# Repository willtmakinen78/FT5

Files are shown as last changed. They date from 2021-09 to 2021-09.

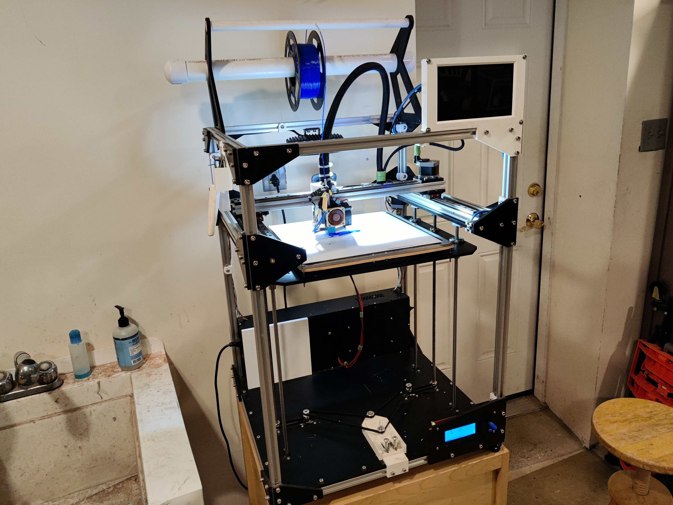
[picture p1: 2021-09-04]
pics/IMG_20210827_170959.jpg

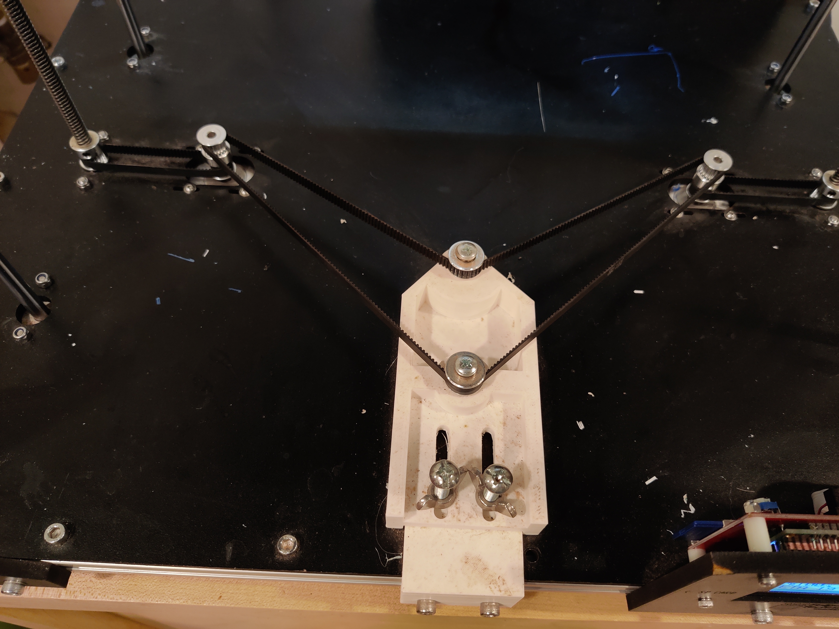
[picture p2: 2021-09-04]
pics/IMG_20210827_171039.jpg

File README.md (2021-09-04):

# FT5
My Very first 3D printer, this is a brief overview of the modifications I've made to my Folgertech FT-5 over the years.

Like the [BCN3D Sigma](https://github.com/willtmakinen78/BCN3DSigma), my work on this machine has been somewhat haphazard and disjointed, so I've done mmy best to collect the most recent version of things here. As my very first machine, this printer has gone through a lot, with many different changes made over the years, both big and small. It was a great learning platform, as it is quite large (300mmx300mmx500mm build volume) with a very open frame, and lent itself quite well to be used for my HIgh school Junior year science fair project which you can check out [here](https://github.com/willtmakinen78/sciencefair2017). If you compare the pcitures between the two, you could somewhat track how it's changed over the years.

#### Here is a list of (most) of the changes I've made:
- Replaced extruder with the E3D Hemera
  - perhaps it's because I'm an E3D shill due to my interning with them, but this is a really great extruder. After going through the stock extruder, the E3D Titan Aero, and a Bondtech Extruder, this has proved to be the best one yet, with the most consistently-good print quality.
  - This is also accompanied by a custom layer fan duct due to the non-standard mounting, similar to the ones on my Sigma printer.
  - an entirely new 3d printed extruder mount was also needed.
 - Aluminum bed mount and BuildTak FlexPlate System
  - the aluminum bed mount provides a super flat base surface for the silicone heater (also added) and the FlexPlate allows for induction probing and easy-to-remove prints
- Induction probe for automatic bed leveling
  - given the era of the FT5 and its price, I don't blame Folgertech too much for not including auto med leveling. After running a BLTouch for a number of years, I wanted something that wouldn't get destroyed if the probe was accidentally left out while an illegal move was being made, so the induction probe is a great solution with no moving parts that triggers perfectly well with the metal FlexPlate.
- Larger overhead spool holder
  - Another feature that has gone through many different iterations, this spolholder, of a size that could only be printed on the FT-5 itself, is finally something that I'm really statisfied with. The bowden tube also prevents the spools from unspooling when you let go of the filament, which is a nice feature.
- Unified Z-axis
  - this one was pulled straight from Thingiverse, but it's a nice little touch that ensures the two Z motors are always moving in sync.
- Integrated RaspberryPi with 7in touch screen
  - I love being able to control my printers from the machines themselves, and this giant touchscreen with a pi running Repeteier Host makes that super easy. It also looks really cool.
- ATX power supply
  - the standard PSU died on me, so I went all out and bought an ATX PSU to replace it (it's a 12V printer). It also has RGB.
- Added TMC2130 stepper drivers
  - replaced the default A4988s with the trinamics to allow for super quiet StealthChop operation and SPI/software-controlled motor currents.
- Improved cable management and wiring harness to the extruder
  - replaced the heavy and drag-prone cable chains with a single wire bundle wrapped in a nice braided sleeve.
- Added print light
  - this is ther same light used for the science fair project. It's meant to be mounted to cars as an auxillary headlight so it's super bright and makes it really easy to see what you're doing and illuminates things very well for the webcam connected to Repetier Host.
- Fully custom Marlin configuration
  - done to keep things updated to the most recent version. The default firware was luckily also a pretty stock Marlin, but Folgertech never really sent out too many updates.
- Fully custom PrusaSlicer Settings
  - This machine has printed GCode from almost any slicer imagineable (Slic3r, Cura, Simplify3D), however PrusaSlicer is my current favorite due to how it handles the differences between machines, gneral print settings, and materials.
- Unified white printed parts
  - tool holders, wire clips, etc. The little things.

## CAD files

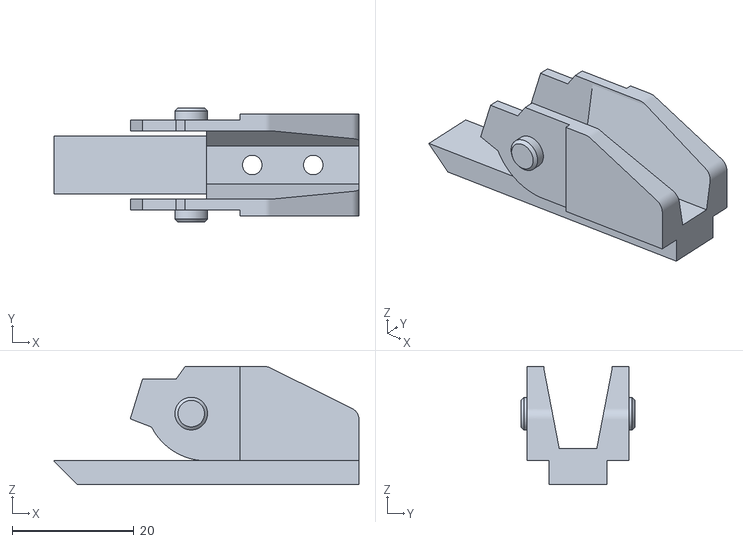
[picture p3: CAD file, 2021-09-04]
cad/Cable_Chain_Mount/Cable_Chain_Mount.stl
50.0 x 18.8 x 19.3

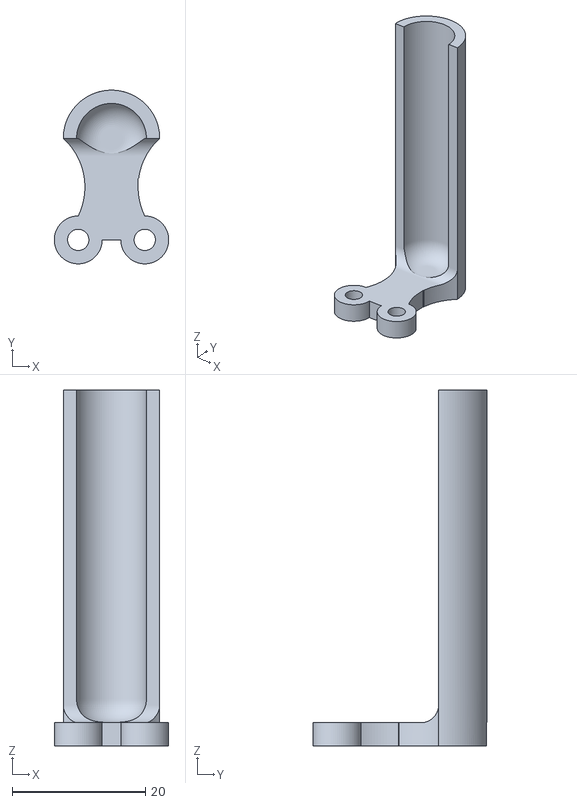
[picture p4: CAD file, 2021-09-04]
cad/Filament_Holders/Extruder_Wire_Holder_R1_1.stl
17.2 x 26.1 x 53.5

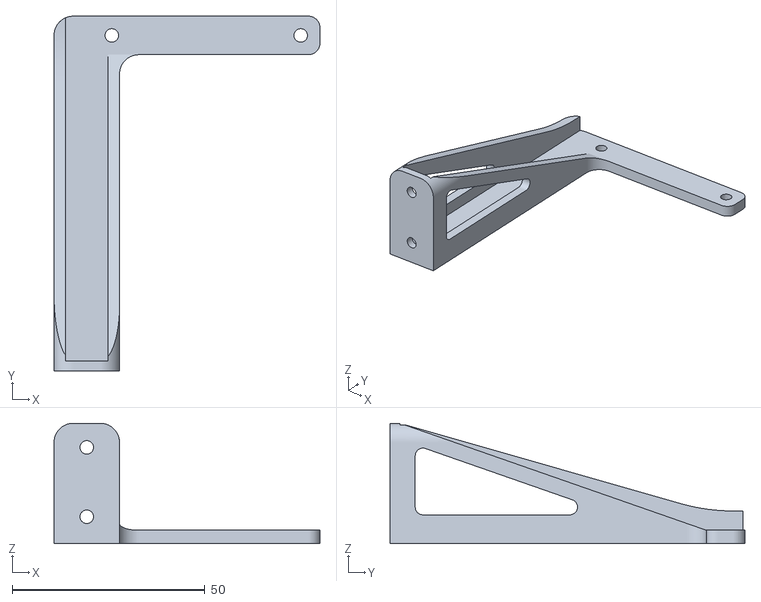
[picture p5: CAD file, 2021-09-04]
cad/FT5_BLTouch_Mount_BMG_Metal_Reinforced/FT5_BLTouch_Mount_BMG_Metal_Reinforced_2.stl
69.0 x 92.0 x 31.2

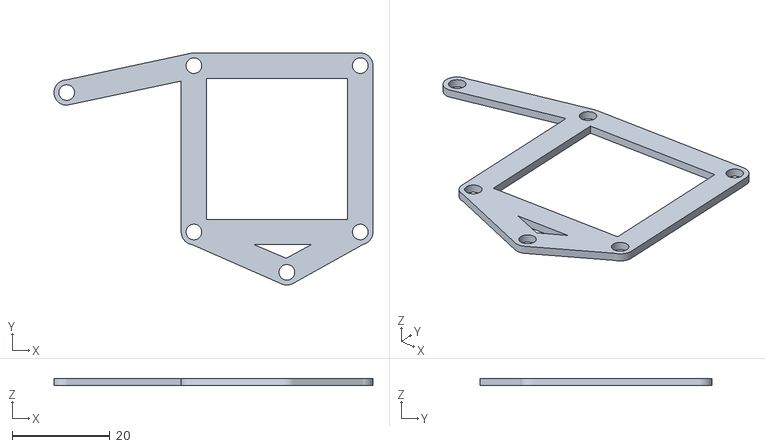
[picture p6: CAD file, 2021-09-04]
cad/Hermes_Mount/Hermes_LayerFan_Mount/Hermes_LayerFan_Mount_Test_1.stl
65.2 x 47.4 x 1.50

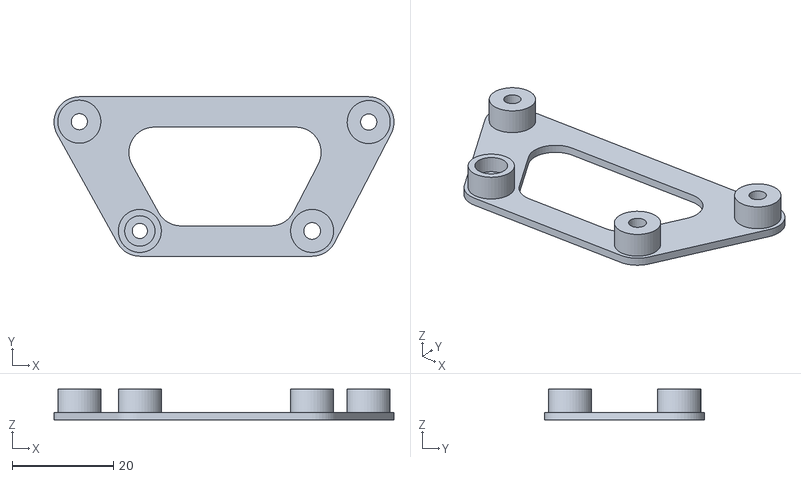
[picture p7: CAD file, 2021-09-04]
cad/Hermes_Mount/Hermes_Mount_Fan/Hemera_5015_FanMount_redangel1984.stl
67.1 x 31.5 x 6.10

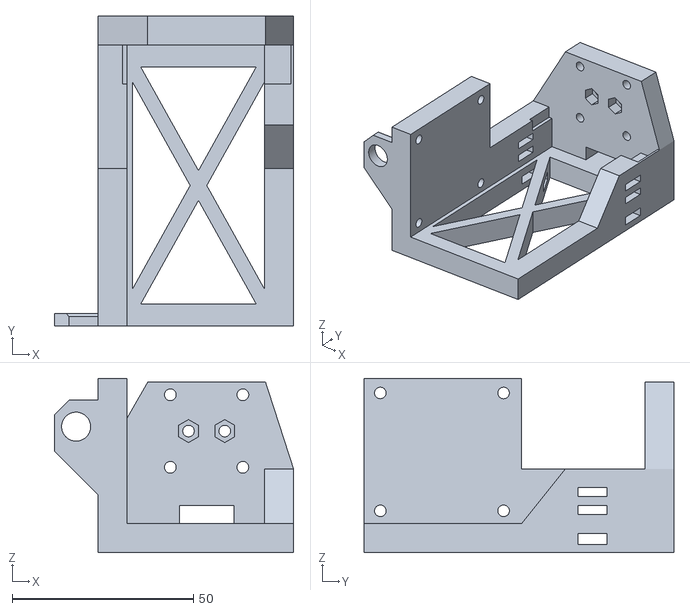
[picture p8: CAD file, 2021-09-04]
cad/Hermes_Mount/Hermes_Mount_Frame/Hermes_Mount_R3.stl
66.0 x 85.5 x 48.0

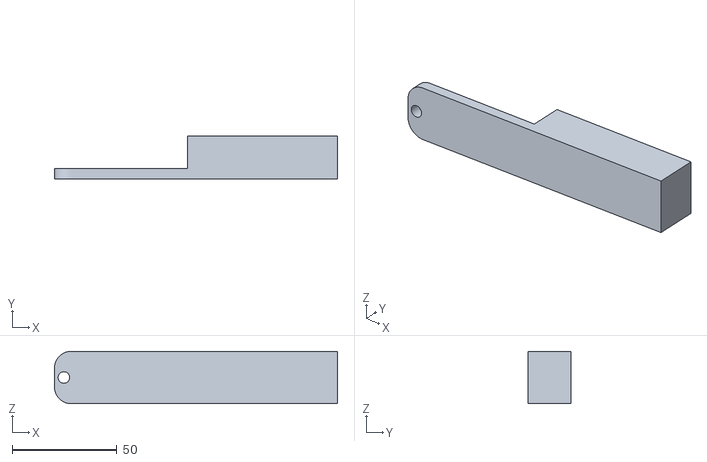
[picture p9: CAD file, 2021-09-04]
cad/Pliers_Holder/Pliers_Holder_Big_1.stl
135.0 x 20.5 x 25.0

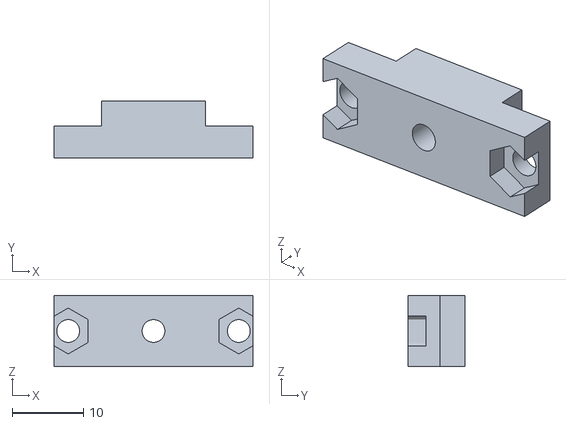
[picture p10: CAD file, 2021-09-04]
cad/Roof_Cable_Holder/Swivel.stl
28.0 x 8.00 x 10.0

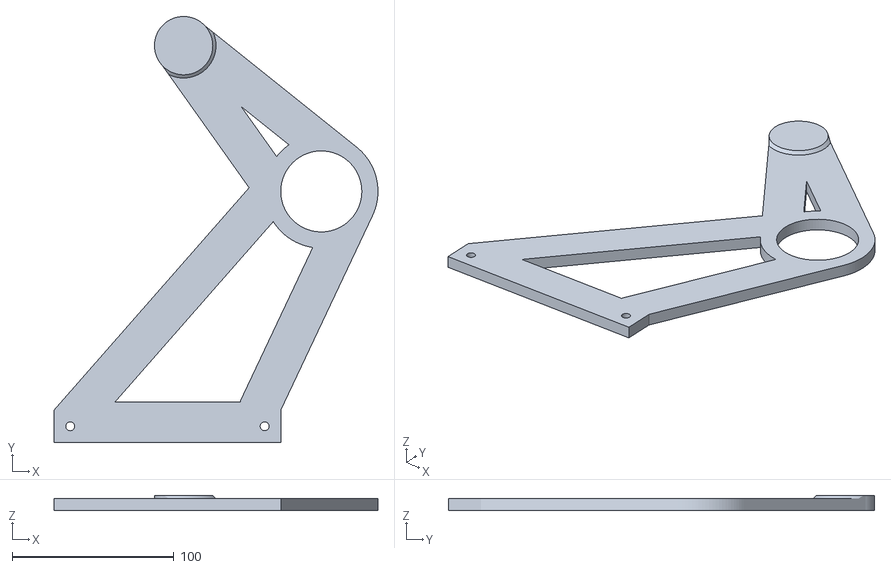
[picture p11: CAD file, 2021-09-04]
cad/Spool_Holder/Spool_Holder.stl
200.0 x 263.0 x 9.50

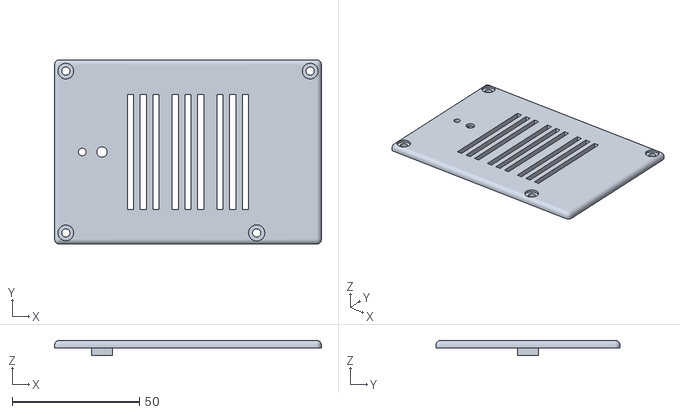
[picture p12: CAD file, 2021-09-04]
cad/TouchScreen_Mount/Raspi7inch_Lid_Switch_1.stl
104.8 x 72.4 x 6.00

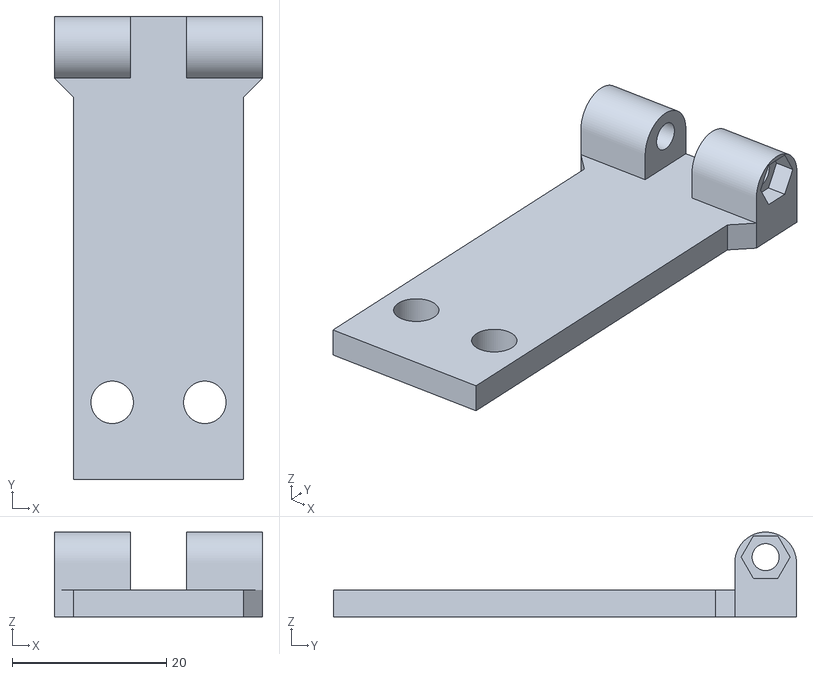
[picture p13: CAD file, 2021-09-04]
cad/Webcam_Mount/FT5_Webcam_Mount_R1.stl
27.0 x 60.0 x 11.0

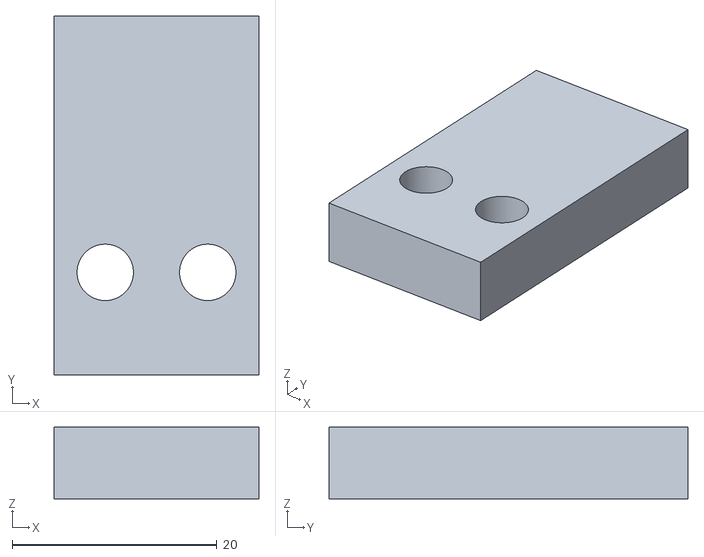
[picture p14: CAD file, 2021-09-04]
cad/Y_Axis_Stopper/Y_Axis_Stopper.stl
20.0 x 35.0 x 7.00

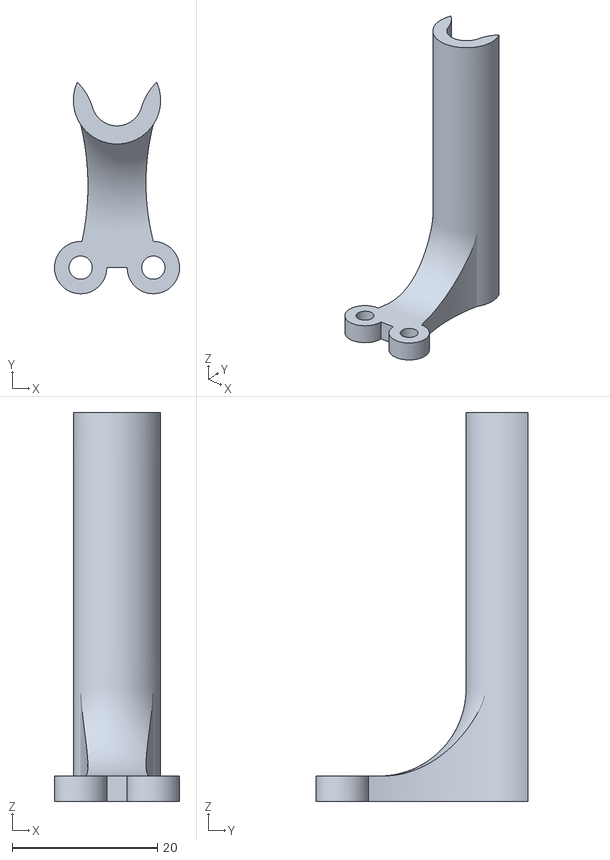
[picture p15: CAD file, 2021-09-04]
cad/Filament_Holders/Extruder_Wire_Holder_1.stl
17.2 x 29.1 x 53.5

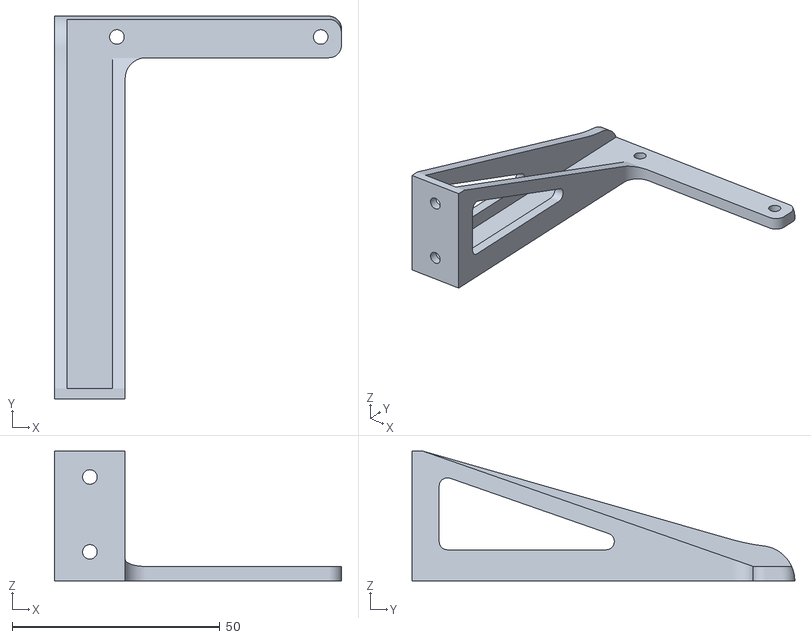
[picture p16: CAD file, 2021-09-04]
cad/FT5_BLTouch_Mount_BMG_Metal_Reinforced/FT5_BLTouch_Mount_BMG_Metal_Reinforced.stl
69.0 x 92.0 x 31.2

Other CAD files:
cad/Hermes_Mount/Hermes_LayerFan_Mount/Hermes_LayerFan_Mount_2.stl
cad/Hermes_Mount/Hermes_Mount_Fan/Hemera_5015_FanDuct_redangel1984_V1.1.1.stl
cad/Hermes_Mount/Hermes_Mount_Frame/X_Axis_Stopper.stl
cad/Roof_Cable_Holder/Loop_X.stl
cad/FT5_BLTouch_Mount_BMG_Metal_Reinforced/FT5_BLTouch_Mount_BMG_Metal_Reinforced_1.stl
cad/FT5_BLTouch_Mount_BMG_Metal_Reinforced/FT5_BLTouch_Mount_BMG_Metal_Reinforced_3.stl
cad/Filament_Holders/Chassis_Bowden_Holder.stl
cad/Filament_Holders/Extruder_Filament_Holder.stl
cad/Filament_Holders/Extruder_Filament_Holder_1.stl
cad/Filament_Holders/Extruder_Filament_Holder_2.stl
cad/Filament_Holders/Extruder_Wire_Holder.stl
cad/Filament_Holders/Extruder_Wire_Holder_R1.stl
cad/Filament_Holders/Extruder_Wire_Holder_R1_2.stl
cad/Filament_Holders/Extruder_Wire_Holder_R1_3.stl
cad/Filament_Holders/Extruder_Wire_Holder_R1_4.stl
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

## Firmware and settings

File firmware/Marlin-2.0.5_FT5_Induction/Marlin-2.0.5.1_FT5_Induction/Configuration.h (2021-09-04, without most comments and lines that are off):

#pragma once
#define CONFIGURATION_H_VERSION 020005
#define STRING_CONFIG_H_AUTHOR "(William Makinen)" // Who made the changes.
#define SHOW_BOOTSCREEN
#define SERIAL_PORT 0
#define BAUDRATE 250000
  #define MOTHERBOARD BOARD_MKS_GEN_13
#define CUSTOM_MACHINE_NAME "FT-5"
#define EXTRUDERS 1
#define DEFAULT_NOMINAL_FILAMENT_DIA 1.75
#define PSU_CONTROL
#define PSU_NAME "Power Supply"
  #define PSU_ACTIVE_HIGH false     // Set 'false' for ATX, 'true' for X-Box
#define TEMP_SENSOR_0 5   //E3D: 5; Generic: 1
#define TEMP_SENSOR_1 0
#define TEMP_SENSOR_2 0
#define TEMP_SENSOR_3 0
#define TEMP_SENSOR_4 0
#define TEMP_SENSOR_5 0
#define TEMP_SENSOR_6 0
#define TEMP_SENSOR_7 0
#define TEMP_SENSOR_BED 1
#define TEMP_SENSOR_PROBE 0
#define TEMP_SENSOR_CHAMBER 0
#define DUMMY_THERMISTOR_998_VALUE 25
#define DUMMY_THERMISTOR_999_VALUE 100
#define MAX_REDUNDANT_TEMP_SENSOR_DIFF 10
#define TEMP_RESIDENCY_TIME     10  // (seconds) Time to wait for hotend to "settle" in M109
#define TEMP_WINDOW              1  // (°C) Temperature proximity for the "temperature reached" timer
#define TEMP_HYSTERESIS          3  // (°C) Temperature proximity considered "close enough" to the target
#define TEMP_BED_RESIDENCY_TIME 10  // (seconds) Time to wait for bed to "settle" in M190
#define TEMP_BED_WINDOW          1  // (°C) Temperature proximity for the "temperature reached" timer
#define TEMP_BED_HYSTERESIS      3  // (°C) Temperature proximity considered "close enough" to the target
#define HEATER_0_MINTEMP   5
#define HEATER_1_MINTEMP   5
#define HEATER_2_MINTEMP   5
#define HEATER_3_MINTEMP   5
#define HEATER_4_MINTEMP   5
#define HEATER_5_MINTEMP   5
#define HEATER_6_MINTEMP   5
#define HEATER_7_MINTEMP   5
#define BED_MINTEMP        5
#define HEATER_0_MAXTEMP 300
#define HEATER_1_MAXTEMP 275
#define HEATER_2_MAXTEMP 275
#define HEATER_3_MAXTEMP 275
#define HEATER_4_MAXTEMP 275
#define HEATER_5_MAXTEMP 275
#define HEATER_6_MAXTEMP 275
#define HEATER_7_MAXTEMP 275
#define BED_MAXTEMP      150
#define PIDTEMP
#define BANG_MAX 255     // Limits current to nozzle while in bang-bang mode; 255=full current
#define PID_MAX BANG_MAX // Limits current to nozzle while PID is active (see PID_FUNCTIONAL_RANGE below); 255=full current
#define PID_K1 0.95      // Smoothing factor within any PID loop
  #define PID_EDIT_MENU         // Add PID editing to the "Advanced Settings" menu. (~700 bytes of PROGMEM)
  #define PID_FUNCTIONAL_RANGE 10 // If the temperature difference between the target temperature and the actual temperature
  #define DEFAULT_Kp 24.60
  #define DEFAULT_Ki 2.45
  #define DEFAULT_Kd 68.01
#define PIDTEMPBED
#define MAX_BED_POWER 255 // limits duty cycle to bed; 255=full current
  #define  DEFAULT_bedKp 75.35
  #define  DEFAULT_bedKi 15.11
  #define  DEFAULT_bedKd 258.52
#define PREVENT_COLD_EXTRUSION
#define EXTRUDE_MINTEMP 170
#define PREVENT_LENGTHY_EXTRUDE
#define EXTRUDE_MAXLENGTH 200
#define THERMAL_PROTECTION_HOTENDS // Enable thermal protection for all extruders
#define THERMAL_PROTECTION_BED     // Enable thermal protection for the heated bed
#define THERMAL_PROTECTION_CHAMBER // Enable thermal protection for the heated chamber
#define USE_XMIN_PLUG
#define USE_YMIN_PLUG
#define USE_ZMIN_PLUG
#define ENDSTOPPULLUPS
#define X_MIN_ENDSTOP_INVERTING true // Set to true to invert the logic of the endstop.
#define Y_MIN_ENDSTOP_INVERTING true // Set to true to invert the logic of the endstop.
#define Z_MIN_ENDSTOP_INVERTING false // Set to true to invert the logic of the endstop.
#define X_MAX_ENDSTOP_INVERTING false // Set to true to invert the logic of the endstop.
#define Y_MAX_ENDSTOP_INVERTING false // Set to true to invert the logic of the endstop.
#define Z_MAX_ENDSTOP_INVERTING false // Set to true to invert the logic of the endstop.
#define Z_MIN_PROBE_ENDSTOP_INVERTING false // Set to true to invert the logic of the probe.
#define X_DRIVER_TYPE TMC2130
#define Y_DRIVER_TYPE TMC2130
#define Z_DRIVER_TYPE TMC2130
#define E0_DRIVER_TYPE TMC2130
#define DEFAULT_AXIS_STEPS_PER_UNIT   { 80, 80, 400, 395 }   // Bondtech: E0 = 418.5, Titan Aero: E0 = 418.5; Generic/no gearing: E0 = 105
#define DEFAULT_MAX_FEEDRATE          { 300, 300, 5, 25 }
#define DEFAULT_MAX_ACCELERATION      { 1000, 1000, 200, 10000 }
#define DEFAULT_ACCELERATION          1000    // X, Y, Z and E acceleration for printing moves
#define DEFAULT_RETRACT_ACCELERATION  3000    // E acceleration for retracts
#define DEFAULT_TRAVEL_ACCELERATION   1000    // X, Y, Z acceleration for travel (non printing) moves
#define CLASSIC_JERK
  #define DEFAULT_XJERK 8.0
  #define DEFAULT_YJERK 8.0
  #define DEFAULT_ZJERK  0.3
#define DEFAULT_EJERK    5.0  // May be used by Linear Advance
#define S_CURVE_ACCELERATION
#define Z_MIN_PROBE_USES_Z_MIN_ENDSTOP_PIN
#define FIX_MOUNTED_PROBE
#define NOZZLE_TO_PROBE_OFFSET { 26, -28, -0.6 }
#define MIN_PROBE_EDGE 10
#define XY_PROBE_SPEED 130*60
#define Z_PROBE_SPEED_FAST HOMING_FEEDRATE_Z / 2
#define Z_PROBE_SPEED_SLOW Z_PROBE_SPEED_FAST / 2
#define MULTIPLE_PROBING 2
#define EXTRA_PROBING    1
#define Z_CLEARANCE_DEPLOY_PROBE   3 // Z Clearance for Deploy/Stow
#define Z_CLEARANCE_BETWEEN_PROBES  3 // Z Clearance between probe points
#define Z_CLEARANCE_MULTI_PROBE     1 // Z Clearance between multiple probes
#define Z_PROBE_LOW_POINT          -10 // Farthest distance below the trigger-point to go before stopping
#define Z_PROBE_OFFSET_RANGE_MIN -20
#define Z_PROBE_OFFSET_RANGE_MAX 20
#define Z_MIN_PROBE_REPEATABILITY_TEST
#define X_ENABLE_ON 0
#define Y_ENABLE_ON 0
#define Z_ENABLE_ON 0
#define E_ENABLE_ON 0 // For all extruders
#define DISABLE_X false
#define DISABLE_Y false
#define DISABLE_Z false
#define DISABLE_E false             // For all extruders
#define DISABLE_INACTIVE_EXTRUDER   // Keep only the active extruder enabled
#define INVERT_X_DIR false
#define INVERT_Y_DIR true
#define INVERT_Z_DIR false
#define INVERT_E0_DIR false
#define INVERT_E1_DIR false
#define INVERT_E2_DIR false
#define INVERT_E3_DIR false
#define INVERT_E4_DIR false
#define INVERT_E5_DIR false
#define INVERT_E6_DIR false
#define INVERT_E7_DIR false
#define X_HOME_DIR -1
#define Y_HOME_DIR -1
#define Z_HOME_DIR -1
#define X_BED_SIZE 297
#define Y_BED_SIZE 305
#define X_MIN_POS 0
#define Y_MIN_POS -10
#define Z_MIN_POS 0
#define X_MAX_POS 298
#define Y_MAX_POS 320
#define Z_MAX_POS 400
#define MIN_SOFTWARE_ENDSTOPS
  #define MIN_SOFTWARE_ENDSTOP_X
  #define MIN_SOFTWARE_ENDSTOP_Y
  #define MIN_SOFTWARE_ENDSTOP_Z
#define MAX_SOFTWARE_ENDSTOPS
  #define MAX_SOFTWARE_ENDSTOP_X
  #define MAX_SOFTWARE_ENDSTOP_Y
  #define MAX_SOFTWARE_ENDSTOP_Z
#define AUTO_BED_LEVELING_LINEAR
  #define GRID_MAX_POINTS_X 3
  #define GRID_MAX_POINTS_Y GRID_MAX_POINTS_X
#define Z_SAFE_HOMING
  #define Z_SAFE_HOMING_X_POINT ((X_BED_SIZE) / 2)    // X point for Z homing when homing all axes (G28).
  #define Z_SAFE_HOMING_Y_POINT ((Y_BED_SIZE) / 2)    // Y point for Z homing when homing all axes (G28).
#define HOMING_FEEDRATE_XY (50*60)
#define HOMING_FEEDRATE_Z  (10*60)
#define VALIDATE_HOMING_ENDSTOPS
#define EEPROM_SETTINGS     // Persistent storage with M500 and M501
#define EEPROM_CHITCHAT       // Give feedback on EEPROM commands. Disable to save PROGMEM.
#define EEPROM_BOOT_SILENT    // Keep M503 quiet and only give errors during first load
#define HOST_KEEPALIVE_FEATURE        // Disable this if your host doesn't like keepalive messages
#define DEFAULT_KEEPALIVE_INTERVAL 2  // Number of seconds between "busy" messages. Set with M113.
#define BUSY_WHILE_HEATING            // Some hosts require "busy" messages even during heating
#define PREHEAT_1_LABEL       "PLA"
#define PREHEAT_1_TEMP_HOTEND 220
#define PREHEAT_1_TEMP_BED     60
#define PREHEAT_1_FAN_SPEED     0 // Value from 0 to 255
#define PREHEAT_2_LABEL       "PET"
#define PREHEAT_2_TEMP_HOTEND 240
#define PREHEAT_2_TEMP_BED    85
#define PREHEAT_2_FAN_SPEED     0 // Value from 0 to 255
#define PRINTJOB_TIMER_AUTOSTART
#define LCD_LANGUAGE en
#define DISPLAY_CHARSET_HD44780 JAPANESE
#define LCD_INFO_SCREEN_STYLE 0
#define SDSUPPORT
#define REPRAP_DISCOUNT_SMART_CONTROLLER
#define SOFT_PWM_SCALE 0
#define SERVO_DELAY { 300 }

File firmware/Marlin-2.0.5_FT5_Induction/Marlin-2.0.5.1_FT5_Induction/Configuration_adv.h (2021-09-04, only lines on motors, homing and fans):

#define E0_AUTO_FAN_PIN -1
#define E1_AUTO_FAN_PIN -1
#define E2_AUTO_FAN_PIN -1
#define E3_AUTO_FAN_PIN -1
#define E4_AUTO_FAN_PIN -1
#define E5_AUTO_FAN_PIN -1
#define CHAMBER_AUTO_FAN_PIN -1
#define X_HOME_BUMP_MM 5
#define Y_HOME_BUMP_MM 5
#define Z_HOME_BUMP_MM 2
#define HOMING_BUMP_DIVISOR { 2, 2, 4 }  // Re-Bump Speed Divisor (Divides the Homing Feedrate)
#define MICROSTEP_MODES { 16, 16, 16, 16, 16, 16 } // [1,2,4,8,16]
#define DIGIPOT_I2C_MOTOR_CURRENTS { 1.0, 1.0, 1.0, 1.0, 1.0, 1.0, 1.0, 1.0 }  //  AZTEEG_X3_PRO
    #define X_CURRENT       800        // (mA) RMS current. Multiply by 1.414 for peak current.
    #define X_CURRENT_HOME  X_CURRENT  // (mA) RMS current for sensorless homing
    #define X_MICROSTEPS     16    // 0..256
    #define Y_CURRENT       900
    #define Y_CURRENT_HOME  Y_CURRENT
    #define Y_MICROSTEPS     16
    #define Z_CURRENT       800
    #define Z_CURRENT_HOME  Z_CURRENT
    #define Z_MICROSTEPS     16
    #define E0_CURRENT      720
    #define E0_MICROSTEPS    16
    #define CURRENT_STEP_DOWN     50  // [mA]
    #define REPORT_CURRENT_CHANGE
  #define X_HYBRID_THRESHOLD     300  // [mm/s]
  #define X2_HYBRID_THRESHOLD    100
  #define Y_HYBRID_THRESHOLD     300
  #define Y2_HYBRID_THRESHOLD    100
  #define Z_HYBRID_THRESHOLD       1
  #define Z2_HYBRID_THRESHOLD      3
  #define Z3_HYBRID_THRESHOLD      3
  #define Z4_HYBRID_THRESHOLD      3
  #define E0_HYBRID_THRESHOLD     100
  #define E1_HYBRID_THRESHOLD     30
  #define E2_HYBRID_THRESHOLD     30
  #define E3_HYBRID_THRESHOLD     30
  #define E4_HYBRID_THRESHOLD     30
  #define E5_HYBRID_THRESHOLD     30
  #define E6_HYBRID_THRESHOLD     30
  #define E7_HYBRID_THRESHOLD     30
  #define SENSORLESS_HOMING // StallGuard capable drivers only
    #define X_STALL_SENSITIVITY  13
    #define X2_STALL_SENSITIVITY X_STALL_SENSITIVITY
    #define Y_STALL_SENSITIVITY  4

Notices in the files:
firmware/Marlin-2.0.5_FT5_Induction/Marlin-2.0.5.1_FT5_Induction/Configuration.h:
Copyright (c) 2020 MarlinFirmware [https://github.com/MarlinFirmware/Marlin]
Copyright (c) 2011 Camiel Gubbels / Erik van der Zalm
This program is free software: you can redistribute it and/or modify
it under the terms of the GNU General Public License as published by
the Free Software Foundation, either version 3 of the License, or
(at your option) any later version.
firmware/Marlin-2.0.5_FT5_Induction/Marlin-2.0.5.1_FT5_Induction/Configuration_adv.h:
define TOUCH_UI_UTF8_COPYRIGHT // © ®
